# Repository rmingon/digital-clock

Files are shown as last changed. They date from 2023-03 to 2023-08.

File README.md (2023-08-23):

# Digital clock

## Just a digital clock with atmega328p + ws2812b + RTC

# FINISH

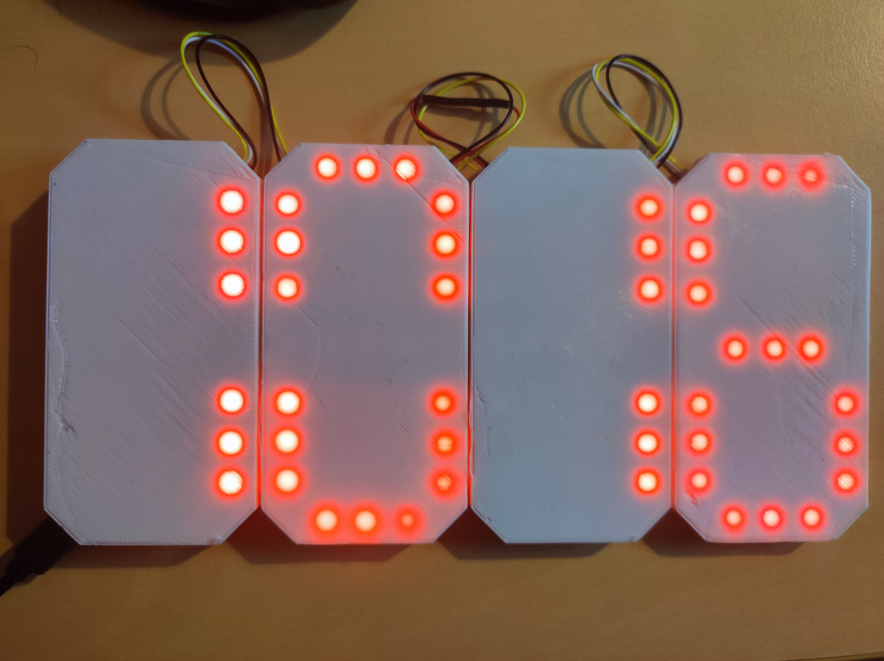
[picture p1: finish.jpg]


# ONE DIGIT -> [VIDEO](https://www.youtube.com/shorts/d32lipOYpTA)

# CHAINED DIGITS -> [VIDEO](https://www.youtube.com/shorts/P1QIr2BeblI)

# CLOCK ON WALL -> [VIDEO](https://www.youtube.com/shorts/ad-uJUUdQWM)

## How to program
### For use this clock you will need to program the mcu via ICSP. (USBASP for example)

## TODO 
- [x] add connector for multiple pcb
- [ ] add capacitor
- [ ] add more light ??
- [ ] ESP8266 ?

### Schematic

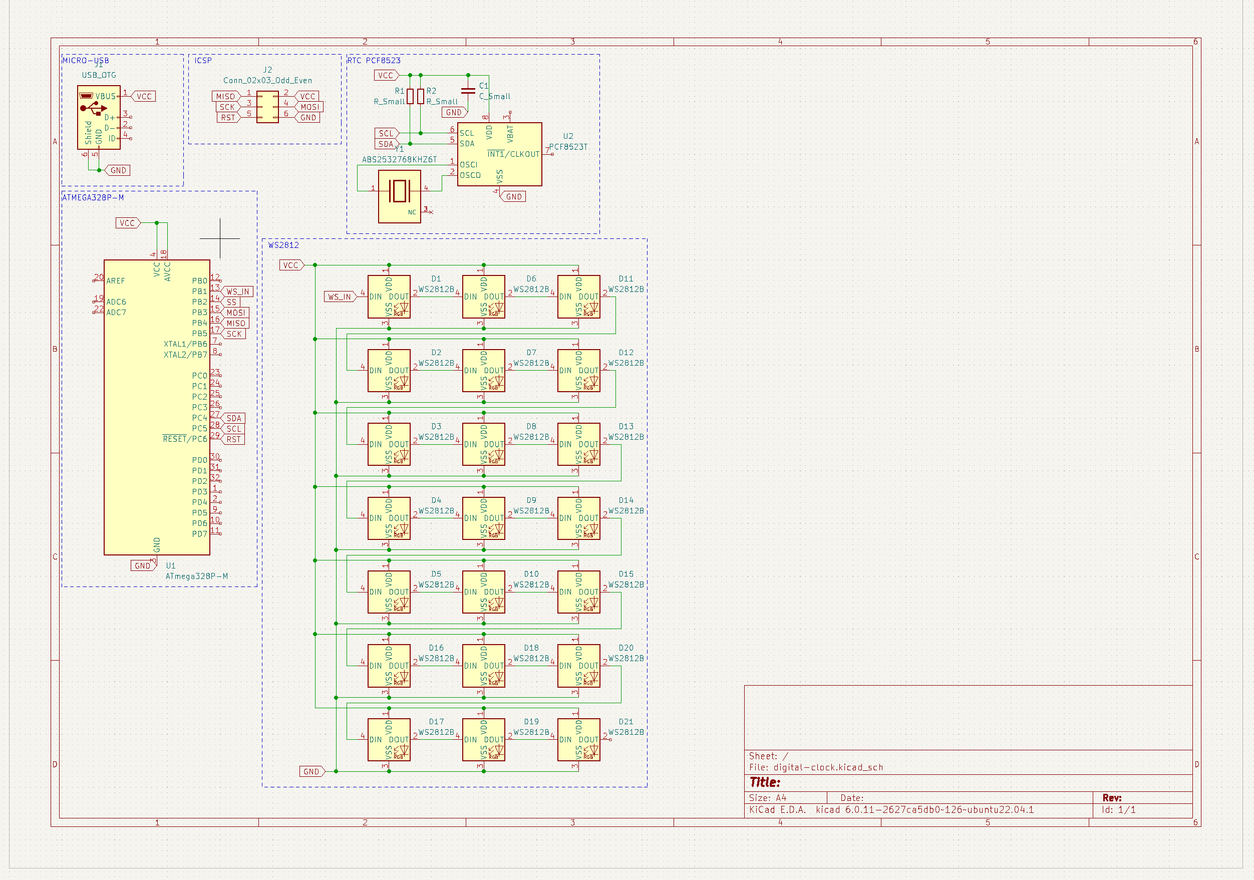
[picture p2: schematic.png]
Schematic


### PCB

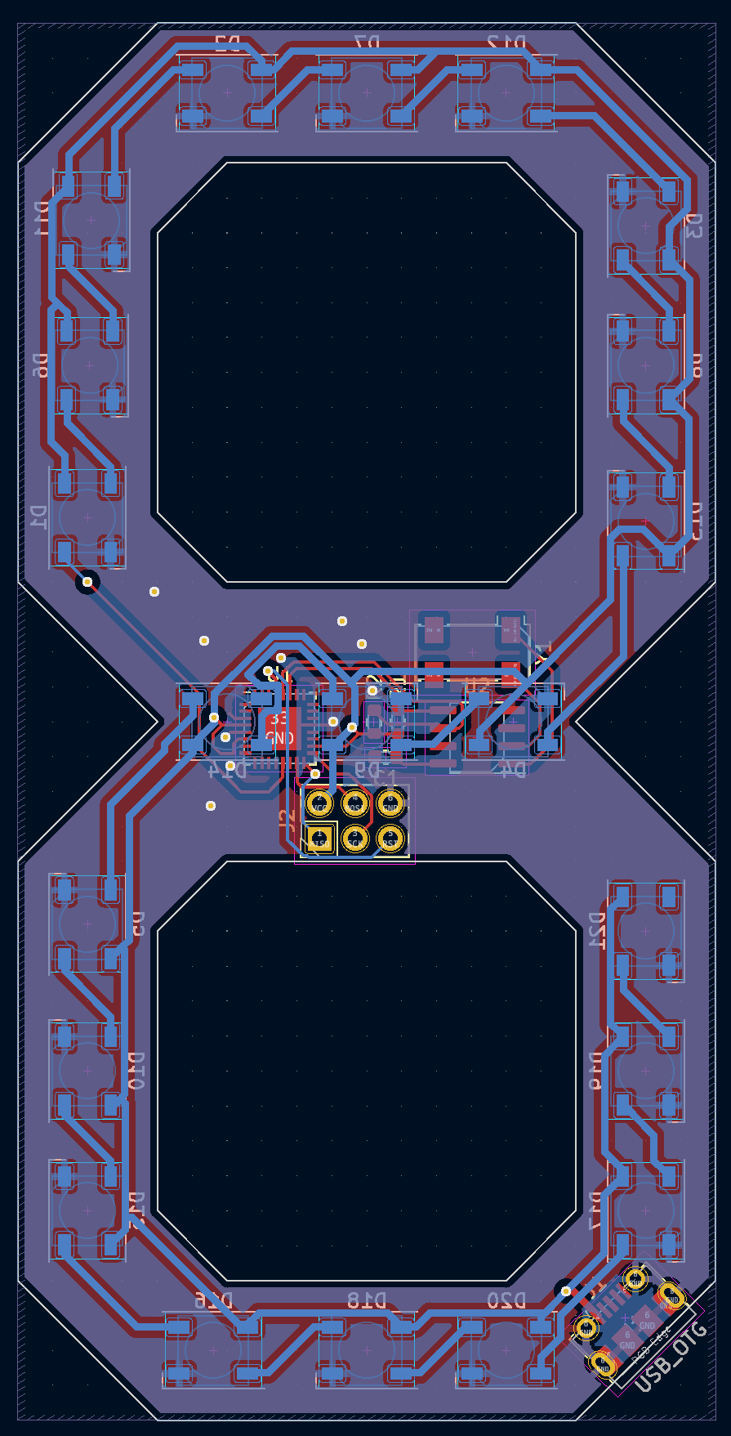
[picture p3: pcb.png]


### 3D Front

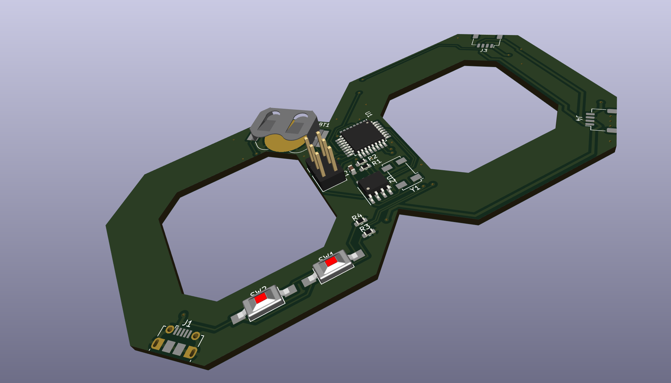
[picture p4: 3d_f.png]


### 3D Back

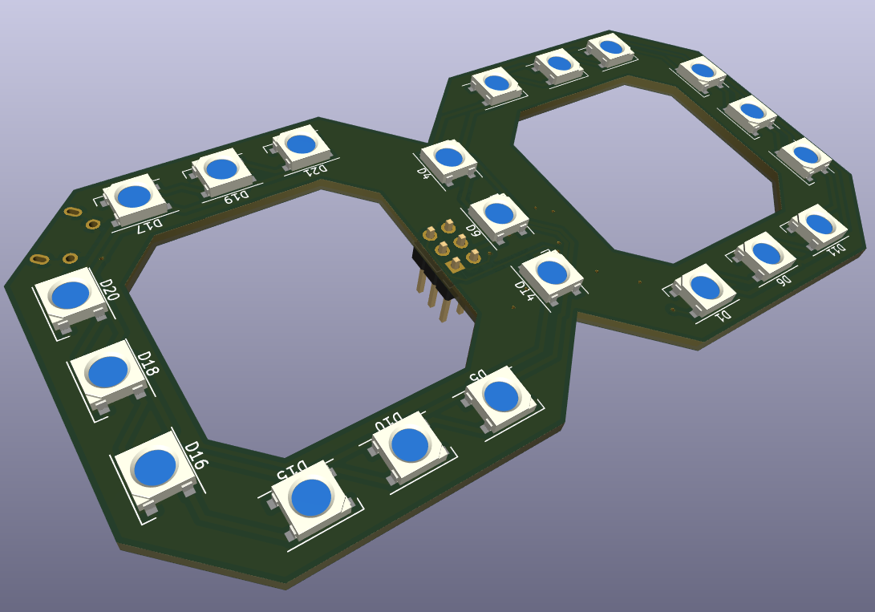
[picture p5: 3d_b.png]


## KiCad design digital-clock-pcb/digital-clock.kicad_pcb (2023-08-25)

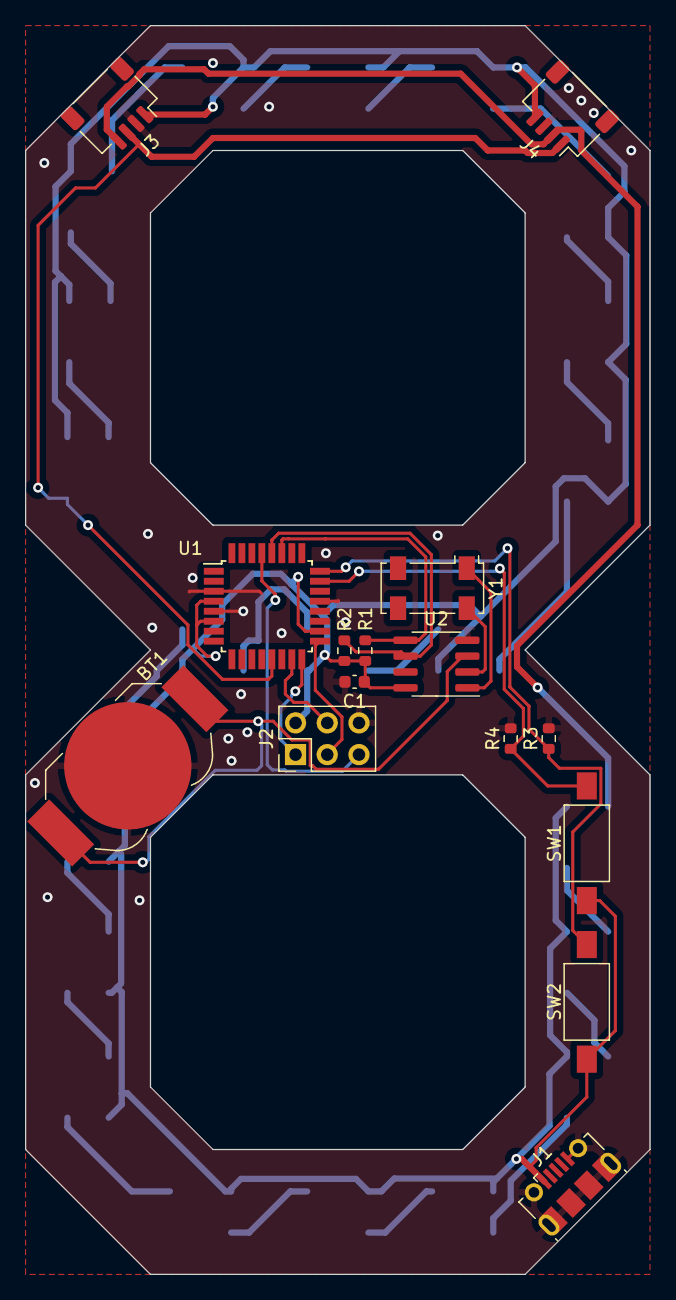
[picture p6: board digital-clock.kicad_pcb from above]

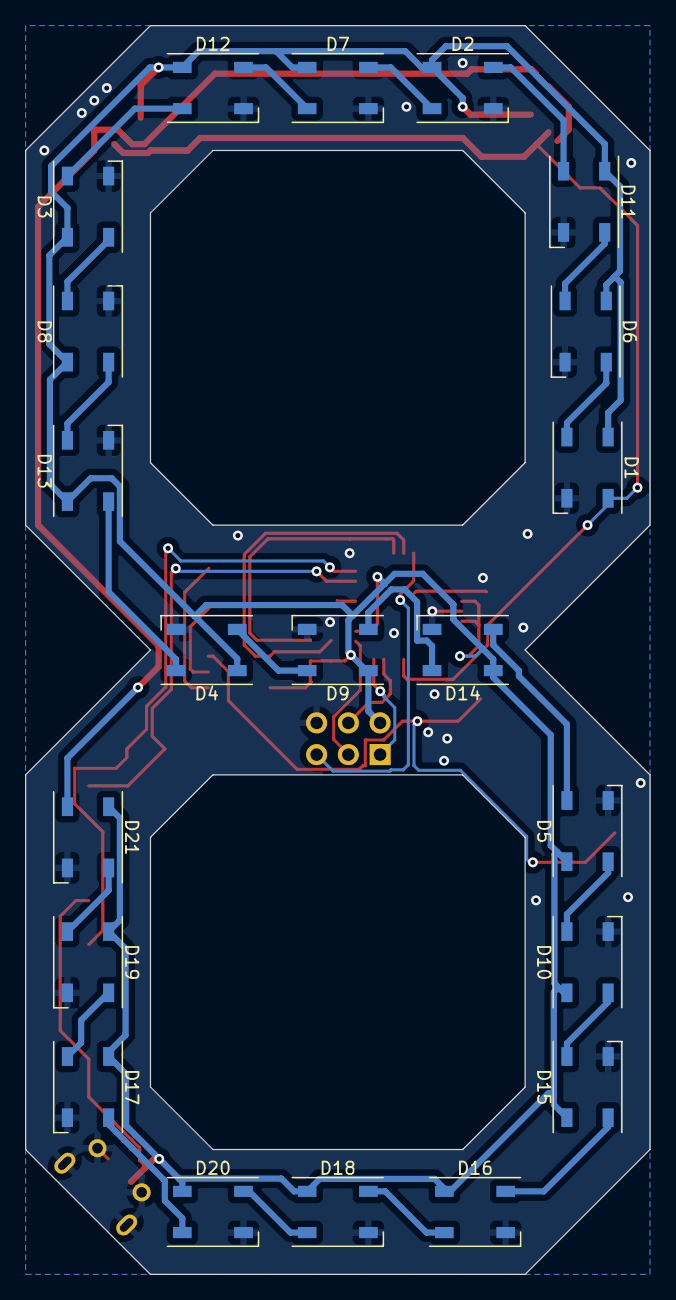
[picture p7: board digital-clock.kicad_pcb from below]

Board: 2 copper layers, 50.0 x 100.0 mm, 36 parts (21 on the bottom side), 35 nets.

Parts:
BT1: Battery_Cell; BatteryHolder_LINX_BAT-HLD-012-SMT
C1: C_Small; C_0603_1608Metric
D1, D2, D3, D4, D5, D6, D7, D8, D9, D10, D11, D12, D13, D14, D15, D16, D17, D18, D19, D20, D21: WS2812B; LED_WS2812B_PLCC4_5.0x5.0mm_P3.2mm
J1: USB_OTG; USB_Micro-B_Molex-105017-0001
J2: Conn_02x03_Odd_Even; PinHeader_2x03_P2.54mm_Vertical
J3, J4: Conn_01x04; JST_SH_SM04B-SRSS-TB_1x04-1MP_P1.00mm_Horizontal
R1, R2, R3, R4: R_Small; R_0603_1608Metric
SW1, SW2: SW_SPST; SW_SPST_FSMSM
U1: ATmega328P-M; TQFP-32_7x7mm_P0.8mm
U2: PCF8523T; SOIC-8_3.9x4.9mm_P1.27mm
Y1: ABS2532768KHZ6T; Crystal_SMD_Abracon_ABS25-4Pin_8.0x3.8mm

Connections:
BTN1: R4.1, SW1.2 (B), U1.23 (PC0)
BTN2: R3.1, SW2.2 (B), U1.24 (PC1)
GND: BT1.2 (-), C1.2, D1.3 (VSS), D2.3 (VSS), D3.3 (VSS), D4.3 (VSS), D5.3 (VSS), D6.3 (VSS), D7.3 (VSS), D8.3 (VSS), D9.3 (VSS), D10.3 (VSS), D11.3 (VSS), D12.3 (VSS), D13.3 (VSS), D14.3 (VSS), D15.3 (VSS), D16.3 (VSS), D17.3 (VSS), D18.3 (VSS), D19.3 (VSS), D20.3 (VSS), D21.3 (VSS), J1.5 (GND), J1.6 (Shield), J2.6, J3.2, J4.3, R3.2, R4.2, U1.3 (GND), U1.5 (GND), U1.21 (GND), U2.4 (VSS)
MISO: J2.1, U1.16 (PB4)
MOSI: J2.4, U1.15 (PB3)
unnamed: BT1.1 (+), U2.3 (VBAT)
unnamed: D1.2 (DOUT), D6.4 (DIN)
unnamed: D2.2 (DOUT), D7.4 (DIN)
unnamed: D3.2 (DOUT), D8.4 (DIN)
unnamed: D4.2 (DOUT), D9.4 (DIN)
unnamed: D5.2 (DOUT), D10.4 (DIN)
unnamed: D10.2 (DOUT), D15.4 (DIN)
unnamed: D6.2 (DOUT), D11.4 (DIN)
unnamed: D2.4 (DIN), D11.2 (DOUT)
unnamed: D7.2 (DOUT), D12.4 (DIN)
unnamed: D3.4 (DIN), D12.2 (DOUT)
unnamed: D8.2 (DOUT), D13.4 (DIN)
unnamed: D4.4 (DIN), D13.2 (DOUT)
unnamed: D9.2 (DOUT), D14.4 (DIN)
unnamed: D5.4 (DIN), D14.2 (DOUT)
unnamed: D15.2 (DOUT), D16.4 (DIN)
unnamed: D16.2 (DOUT), D18.4 (DIN)
unnamed: D17.4 (DIN), D20.2 (DOUT)
unnamed: D17.2 (DOUT), D19.4 (DIN)
unnamed: D18.2 (DOUT), D20.4 (DIN)
unnamed: D19.2 (DOUT), D21.4 (DIN)
unnamed: U2.1 (OSCI), Y1.1
unnamed: U2.2 (OSCO), Y1.4
RST: J2.5, U1.29 (~RESET/PC6)
SCK: J2.3, U1.17 (PB5)
SCL: R2.2, U1.28 (PC5), U2.6 (SCL)
SDA: R1.2, U1.27 (PC4), U2.5 (SDA)
VCC: C1.1, D1.1 (VDD), D2.1 (VDD), D3.1 (VDD), D4.1 (VDD), D5.1 (VDD), D6.1 (VDD), D7.1 (VDD), D8.1 (VDD), D9.1 (VDD), D10.1 (VDD), D11.1 (VDD), D12.1 (VDD), D13.1 (VDD), D14.1 (VDD), D15.1 (VDD), D16.1 (VDD), D17.1 (VDD), D18.1 (VDD), D19.1 (VDD), D20.1 (VDD), D21.1 (VDD), J1.1 (VBUS), J2.2, J3.1, J4.4, R1.1, R2.1, SW1.1 (A), SW2.1 (A), U1.4 (VCC), U1.6 (VCC), U1.18 (AVCC), U2.8 (VDD)
WS_IN: D1.4 (DIN), J3.3, J4.1, U1.13 (PB1)
WS_OUT: D21.2 (DOUT), J3.4, J4.2

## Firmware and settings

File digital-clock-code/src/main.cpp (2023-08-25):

#include <Arduino.h>
#include <NeoPixelBus.h>
#include <MCP7940.h>

#define LED_BY_SEGMENT 3
#define SEGMENT 7
#define DIGIT 4

#define MINUTE_PIN 14
#define HOUR_PIN 15

#define SEVEN_SEGMENT 8

int one[] = {0, 2};
int two[] = {3, 5};
int three[] = {6, 8};
int four[] = {9, 11};
int five[] = {12, 14};
int six[] = {15, 17};
int seven[] = {18, 20};

int digit_zero[6] = {0, 1, 2, 4, 5, 6};
int digit_one[2] = {0, 4};
int digit_two[5] = {0, 1, 3, 5, 6};
int digit_three[5] = {0, 1, 3, 4, 5};
int digit_four[4] = {0, 2, 3, 4};
int digit_five[5] = {1, 2, 3, 4, 5};
int digit_six[6] = {1, 2, 3, 4, 5, 6};
int digit_seven[3] = {0, 1, 4};
int digit_eight[7] = {0, 1, 2, 3, 4, 5, 6};
int digit_nine[6] = {0, 1, 2, 3, 4, 5};

int hour = 0;
int minute = 0;

const uint16_t PixelCount = LED_BY_SEGMENT * SEGMENT * DIGIT; // this example assumes 4 pixels, making it smaller will cause a failure
const uint8_t PixelPin = 9;  // make sure to set this to the correct pin, ignored for Esp8266

int colorSaturation = 30;

MCP7940_Class MCP7940;

// three element pixels, in different order and speeds
NeoPixelBus<NeoGrbFeature, NeoWs2812xMethod> strip(PixelCount, PixelPin);

RgbColor red(colorSaturation, 0, 0);
RgbColor green(0, colorSaturation, 0);
RgbColor blue(0, 0, colorSaturation);
RgbColor white(colorSaturation);
RgbColor black(0);

HslColor hslRed(red);
HslColor hslGreen(green);
HslColor hslBlue(blue);
HslColor hslWhite(white);
HslColor hslBlack(black);

RgbColor randomColor();
int* getNumberFromInt(int);
int getSegment(int);
void setDigit(int *, int, int);

void resetDigit(int position) {
  for(int i = (LED_BY_SEGMENT * SEGMENT * (position - 1)); i < (LED_BY_SEGMENT * SEGMENT * (position)); i++){
    strip.SetPixelColor(i, black);
    strip.Show();
  }
  
}

void setup()
{

  pinMode(MINUTE_PIN, INPUT);
  pinMode(HOUR_PIN, INPUT);
 
  strip.Begin();
  strip.SetPixelColor(0, red);
  strip.Show();
  
  while (!MCP7940.begin()) {
    strip.SetPixelColor(0, white);
    strip.Show();
  }
  
  while (!MCP7940.deviceStatus()) {
    bool deviceStatus = MCP7940.deviceStart();
    if (!deviceStatus) {
     strip.SetPixelColor(0, blue);
     strip.Show();
    }
  }
  MCP7940.adjust();
}


void loop()
{
  DateTime now = MCP7940.now();

  if (now.minute() != minute) {
    unsigned first_minute = (now.minute() / 10U) % 10;
    unsigned second_minute = (now.minute() / 1U) % 10;
    setDigit(getNumberFromInt(first_minute), getSegment(first_minute), 3);
    setDigit(getNumberFromInt(second_minute), getSegment(second_minute), 4);
    minute = now.minute();
  }
  
  if (now.hour() != hour) {
    if (now.hour() > 22 || now.hour() < 7) {
      colorSaturation = 20;
    } else {
      colorSaturation = 50;
    }
    unsigned first_hour = (now.hour() / 10U) % 10;
    unsigned second_hour = (now.hour() / 1U) % 10;
    setDigit(getNumberFromInt(first_hour), getSegment(first_hour), 1);
    setDigit(getNumberFromInt(second_hour), getSegment(second_hour), 2);
    hour = now.hour();
  }



  if (digitalRead(MINUTE_PIN) == HIGH) {
    MCP7940.adjust(DateTime(now.year(), now.month(), now.day(), now.hour(), now.minute() + 1, now.second()));
    delay(200);
  }

  if (digitalRead(HOUR_PIN) == HIGH) {
    MCP7940.adjust(DateTime(now.year(), now.month(), now.day(), now.hour() + 1, now.minute(), now.second()));
    delay(400);
  }
}

void setDigit(int *digit, int segment, int position) {
  resetDigit(position);
  for(int i = 0; i < segment; i++) {
    strip.SetPixelColor((digit[i]*3)+(LED_BY_SEGMENT * SEGMENT * (position - 1)), randomColor());
    strip.SetPixelColor((digit[i]*3+1)+(LED_BY_SEGMENT * SEGMENT * (position - 1)), randomColor());
    strip.SetPixelColor((digit[i]*3+2)+(LED_BY_SEGMENT * SEGMENT * (position - 1)), randomColor());
  }
  strip.Show();
}

RgbColor randomColor() {
  return RgbColor (random(30, 150), random(30, 150), random(30, 150));
}

int* getNumberFromInt(int number) {
  if (number == 0) {
    return digit_zero;
  } else if (number == 1) {
    return digit_one;
  } else if (number == 2) {
    return digit_two;
  } else if (number == 3) {
    return digit_three;
  } else if (number == 4) {
    return digit_four;
  } else if (number == 5) {
    return digit_five;
  } else if (number == 6) {
    return digit_six;
  } else if (number == 7) {
    return digit_seven;
  } else if (number == 8) {
    return digit_eight;
  } else if (number == 9) {
    return digit_nine;
  }
}

int getSegment(int number) {
  if (number == 0) {
    return 6;
  } else if (number == 1) {
    return 2;
  } else if (number == 2) {
    return 5;
  } else if (number == 3) {
    return 5;
  } else if (number == 4) {
    return 4;
  } else if (number == 5) {
    return 5;
  } else if (number == 6) {
    return 6;
  } else if (number == 7) {
    return 3;
  } else if (number == 8) {
    return 7;
  } else if (number == 9) {
    return 6;
  }
}

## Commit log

2023-03-28 init project
    [digital-clock.kicad_pcb, digital-clock.kicad_sch]
2023-03-30 add pcb
    [digital-clock.kicad_sch]
2023-03-30 update silkscreen
    [digital-clock.kicad_pcb]
2023-06-16 add connector
    [digital-clock.kicad_sch]
2023-06-16 wiring connector
    [digital-clock.kicad_pcb, digital-clock.kicad_sch]
2023-07-01 change m328 package
    [digital-clock.kicad_pcb, digital-clock.kicad_sch]
2023-07-18 add clock battery + add button for change hour and minute
    [digital-clock.kicad_pcb, digital-clock.kicad_sch]
2023-08-23 add gnd usb
    [digital-clock.kicad_pcb]
2023-08-25 update pcb
    [digital-clock.kicad_pcb]
